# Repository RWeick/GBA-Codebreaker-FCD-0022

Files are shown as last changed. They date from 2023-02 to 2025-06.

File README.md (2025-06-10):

# Blaze Xploder SP and Codebreaker FCD-0022
The full schematic, PCB, and flash dumps of the GBA Codebreaker and Xploder SP. Both use the same PCB and CPLD. The original PCB is a 4-layer PCB, though it isn't necessary in order to route everything.

PCB Thickness: 0.8 mm

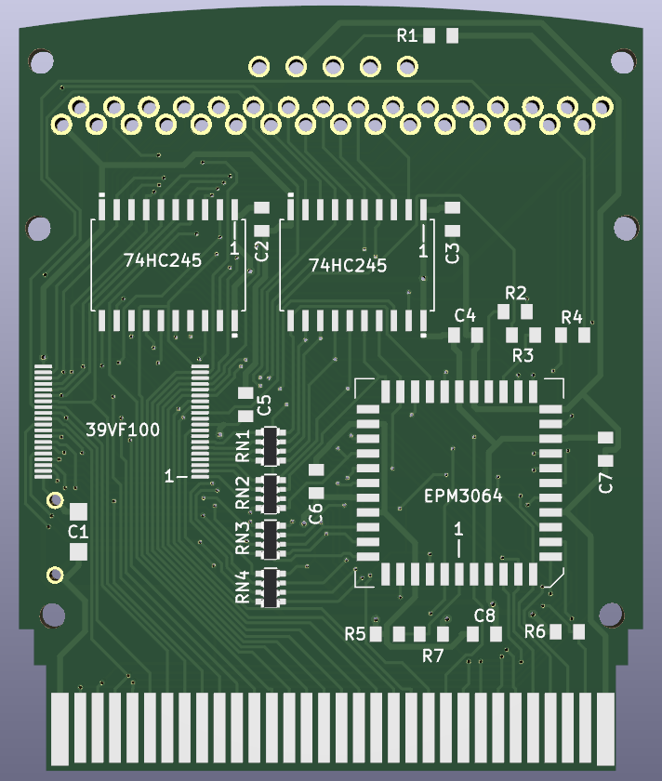
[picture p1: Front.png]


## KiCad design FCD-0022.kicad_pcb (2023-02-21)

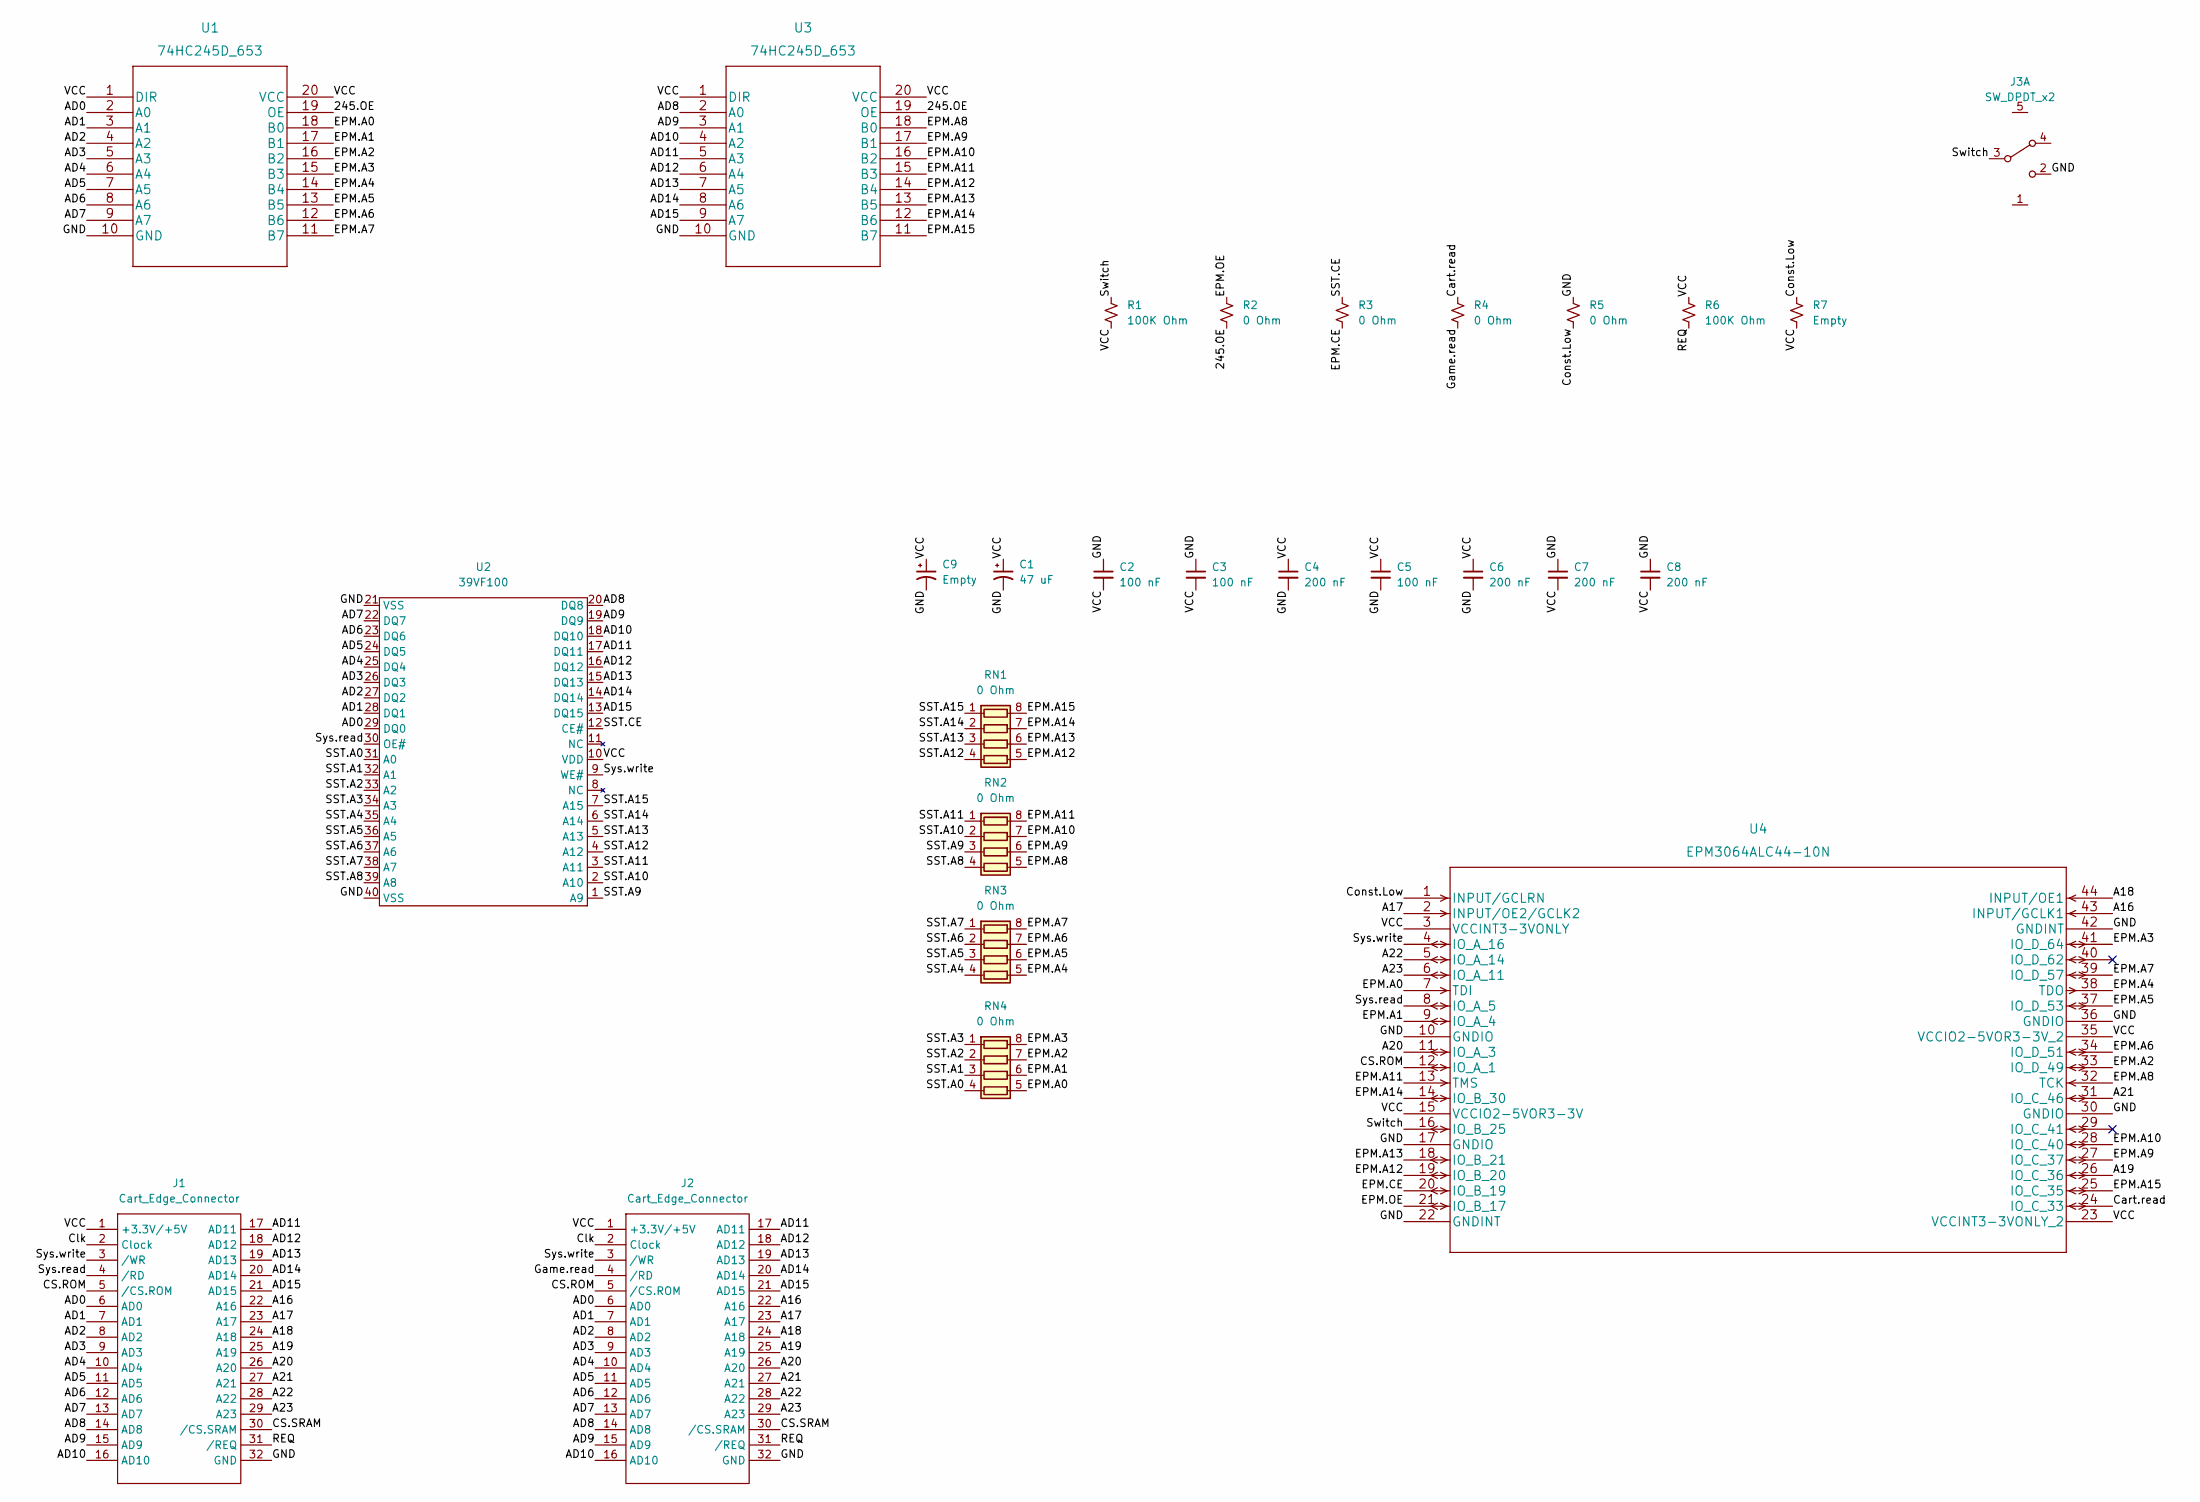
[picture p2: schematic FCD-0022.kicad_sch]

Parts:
C1: 47 uF; Codebreaker 47 uF Pad
C2, C3, C5: 100 nF; Codebreaker Cap-Res
C4, C6, C7, C8: 200 nF; Codebreaker Cap-Res
C9: Empty; Codebreaker Cap TH
J1: Cart_Edge_Connector; ACTUAL GAMEBOY EDGE CONNECTOR
J2: Cart_Edge_Connector; Cartridge Slot, GBC
J3: SW_DPDT_x2; Codebreaker Switch
R1, R6: 100K Ohm; Codebreaker Cap-Res
R2, R3, R4, R5: 0 Ohm; Codebreaker Cap-Res
R7: Empty; Codebreaker Cap-Res
RN1, RN2, RN3, RN4: 0 Ohm; R_Array_Convex_4x0603
U1, U3: 74HC245D_653
U2: 39VF100; Codebreaker 39VF100
U4: EPM3064ALC44-10N; PLCC-44

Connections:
/245.OE: R2.2, U1.19 (OE), U3.19 (OE)
/A16: J1.22 (A16), J2.22 (A16), U4.43 (INPUT/GCLK1)
/A17: J1.23 (A17), J2.23 (A17), U4.2 (INPUT/OE2/GCLK2)
/A18: J1.24 (A18), J2.24 (A18), U4.44 (INPUT/OE1)
/A19: J1.25 (A19), J2.25 (A19), U4.26 (IO_C_36)
/A20: J1.26 (A20), J2.26 (A20), U4.11 (IO_A_3)
/A21: J1.27 (A21), J2.27 (A21), U4.31 (IO_C_46)
/A22: J1.28 (A22), J2.28 (A22), U4.5 (IO_A_14)
/A23: J1.29 (A23), J2.29 (A23), U4.6 (IO_A_11)
/AD0: J1.6 (AD0), J2.6 (AD0), U1.2 (A0), U2.29 (DQ0)
/AD1: J1.7 (AD1), J2.7 (AD1), U1.3 (A1), U2.28 (DQ1)
/AD2: J1.8 (AD2), J2.8 (AD2), U1.4 (A2), U2.27 (DQ2)
/AD3: J1.9 (AD3), J2.9 (AD3), U1.5 (A3), U2.26 (DQ3)
/AD4: J1.10 (AD4), J2.10 (AD4), U1.6 (A4), U2.25 (DQ4)
/AD5: J1.11 (AD5), J2.11 (AD5), U1.7 (A5), U2.24 (DQ5)
/AD6: J1.12 (AD6), J2.12 (AD6), U1.8 (A6), U2.23 (DQ6)
/AD7: J1.13 (AD7), J2.13 (AD7), U1.9 (A7), U2.22 (DQ7)
/AD8: J1.14 (AD8), J2.14 (AD8), U2.20 (DQ8), U3.2 (A0)
/AD9: J1.15 (AD9), J2.15 (AD9), U2.19 (DQ9), U3.3 (A1)
/AD10: J1.16 (AD10), J2.16 (AD10), U2.18 (DQ10), U3.4 (A2)
/AD11: J1.17 (AD11), J2.17 (AD11), U2.17 (DQ11), U3.5 (A3)
/AD12: J1.18 (AD12), J2.18 (AD12), U2.16 (DQ12), U3.6 (A4)
/AD13: J1.19 (AD13), J2.19 (AD13), U2.15 (DQ13), U3.7 (A5)
/AD14: J1.20 (AD14), J2.20 (AD14), U2.14 (DQ14), U3.8 (A6)
/AD15: J1.21 (AD15), J2.21 (AD15), U2.13 (DQ15), U3.9 (A7)
/CS.ROM: J1.5 (/CS.ROM), J2.5 (/CS.ROM), U4.12 (IO_A_1)
/CS.SRAM: J1.30 (/CS.SRAM), J2.30 (/CS.SRAM)
/Cart.read: R4.1, U4.24 (IO_C_33)
/Clk: J1.2 (Clock), J2.2 (Clock)
/Const.Low: R5.2, R7.1, U4.1 (INPUT/GCLRN)
/EPM.A0: RN4.5 (R4.2), U1.18 (B0), U4.7 (TDI)
/EPM.A1: RN4.6 (R3.2), U1.17 (B1), U4.9 (IO_A_4)
/EPM.A2: RN4.7 (R2.2), U1.16 (B2), U4.33 (IO_D_49)
/EPM.A3: RN4.8 (R1.2), U1.15 (B3), U4.41 (IO_D_64)
/EPM.A4: RN3.5 (R4.2), U1.14 (B4), U4.38 (TDO)
/EPM.A5: RN3.6 (R3.2), U1.13 (B5), U4.37 (IO_D_53)
/EPM.A6: RN3.7 (R2.2), U1.12 (B6), U4.34 (IO_D_51)
/EPM.A7: RN3.8 (R1.2), U1.11 (B7), U4.39 (IO_D_57)
/EPM.A8: RN2.5 (R4.2), U3.18 (B0), U4.32 (TCK)
/EPM.A9: RN2.6 (R3.2), U3.17 (B1), U4.27 (IO_C_37)
/EPM.A10: RN2.7 (R2.2), U3.16 (B2), U4.28 (IO_C_40)
/EPM.A11: RN2.8 (R1.2), U3.15 (B3), U4.13 (TMS)
/EPM.A12: RN1.5 (R4.2), U3.14 (B4), U4.19 (IO_B_20)
/EPM.A13: RN1.6 (R3.2), U3.13 (B5), U4.18 (IO_B_21)
/EPM.A14: RN1.7 (R2.2), U3.12 (B6), U4.14 (IO_B_30)
/EPM.A15: RN1.8 (R1.2), U3.11 (B7), U4.25 (IO_C_35)
/EPM.CE: R3.2, U4.20 (IO_B_19)
/EPM.OE: R2.1, U4.21 (IO_B_17)
/GND: C1.2, C2.1, C3.1, C4.2, C5.2, C6.2, C7.1, C8.1, C9.2, J1.32 (GND), J2.32 (GND), J3.2 (C), R5.1, U1.10 (GND), U2.21 (VSS), U2.40 (VSS), U3.10 (GND), U4.10 (GNDIO), U4.17 (GNDIO), U4.22 (GNDINT), U4.30 (GNDIO), U4.36 (GNDIO), U4.42 (GNDINT)
/Game.read: J2.4 (/RD), R4.2
/REQ: J1.31 (/REQ), J2.31 (/REQ), R6.2
/SST.A0: RN4.4 (R4.1), U2.31 (A0)
/SST.A1: RN4.3 (R3.1), U2.32 (A1)
/SST.A2: RN4.2 (R2.1), U2.33 (A2)
/SST.A3: RN4.1 (R1.1), U2.34 (A3)
/SST.A4: RN3.4 (R4.1), U2.35 (A4)
/SST.A5: RN3.3 (R3.1), U2.36 (A5)
/SST.A6: RN3.2 (R2.1), U2.37 (A6)
/SST.A7: RN3.1 (R1.1), U2.38 (A7)
/SST.A8: RN2.4 (R4.1), U2.39 (A8)
/SST.A9: RN2.3 (R3.1), U2.1 (A9)
/SST.A10: RN2.2 (R2.1), U2.2 (A10)
/SST.A11: RN2.1 (R1.1), U2.3 (A11)
/SST.A12: RN1.4 (R4.1), U2.4 (A12)
/SST.A13: RN1.3 (R3.1), U2.5 (A13)
/SST.A14: RN1.2 (R2.1), U2.6 (A14)
/SST.A15: RN1.1 (R1.1), U2.7 (A15)
/SST.CE: R3.1, U2.12 (CE#)
/Switch: J3.3 (B), R1.1, U4.16 (IO_B_25)
/Sys.read: J1.4 (/RD), U2.30 (OE#), U4.8 (IO_A_5)
/Sys.write: J1.3 (/WR), J2.3 (/WR), U2.9 (WE#), U4.4 (IO_A_16)
/VCC: C1.1, C2.2, C3.2, C4.1, C5.1, C6.1, C7.2, C8.2, C9.1, J1.1 (+3.3V/+5V), J2.1 (+3.3V/+5V), R1.2, R6.1, R7.2, U1.1 (DIR), U1.20 (VCC), U2.10 (VDD), U3.1 (DIR), U3.20 (VCC), U4.3 (VCCINT3-3VONLY), U4.15 (VCCIO2-5VOR3-3V), U4.23 (VCCINT3-3VONLY_2), U4.35 (VCCIO2-5VOR3-3V_2)

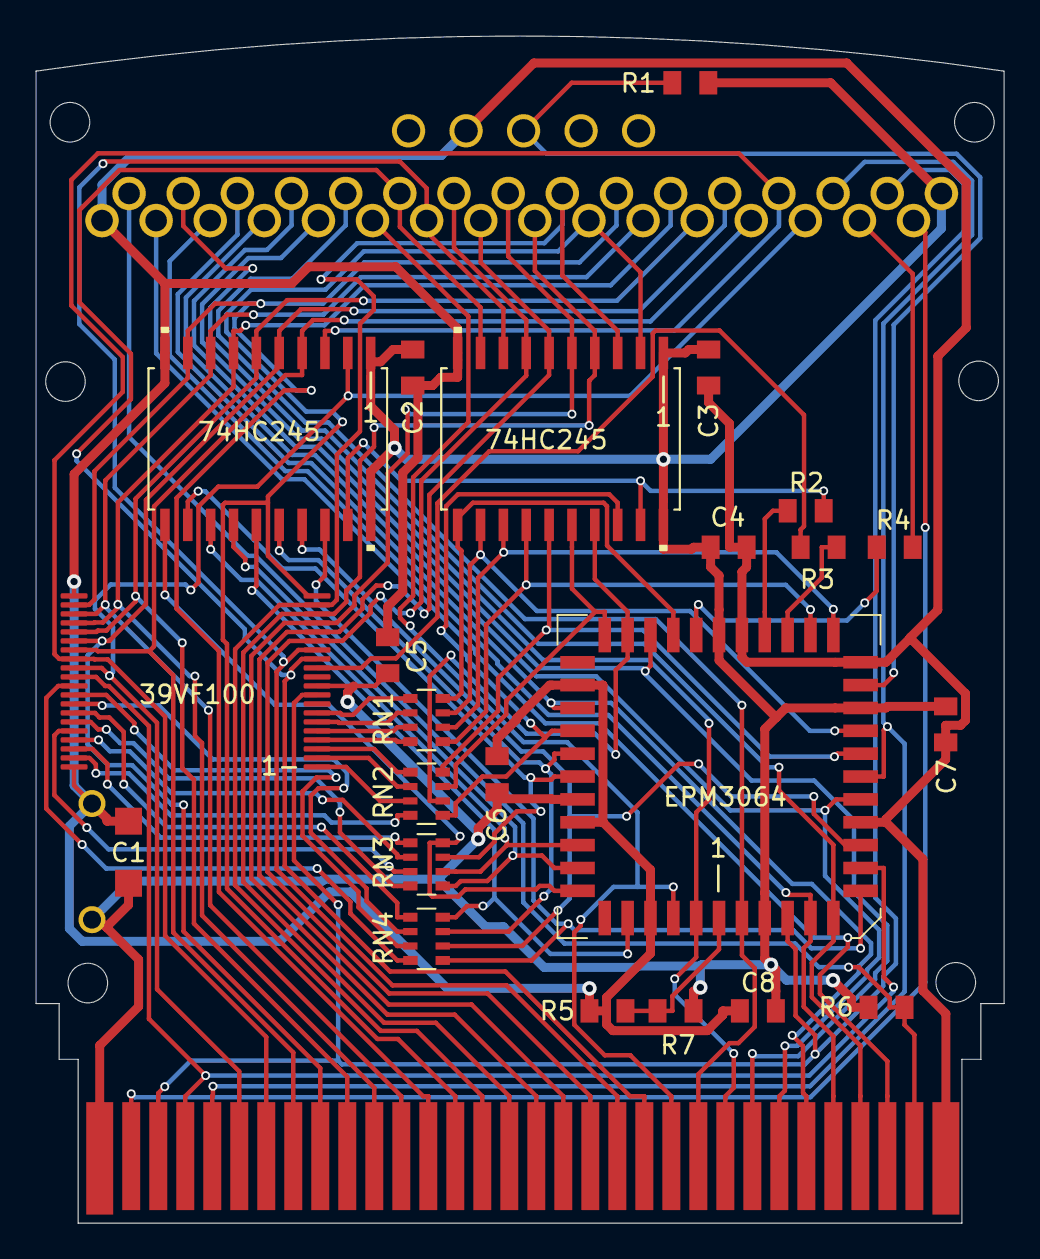
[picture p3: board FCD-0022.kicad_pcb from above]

Board: 2 copper layers, 53.8 x 66.0 mm, 33 parts (0 on the bottom side), 72 nets.

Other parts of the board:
H1, H2, H3, H4, H5, H6: MountingHole_2.2mm_M2

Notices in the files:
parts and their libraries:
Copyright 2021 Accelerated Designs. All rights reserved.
